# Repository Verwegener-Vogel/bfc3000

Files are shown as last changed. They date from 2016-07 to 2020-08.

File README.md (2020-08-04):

# bfc3000
## Watch and analyze your [local wild bird's](https://upload.wikimedia.org/wikipedia/commons/8/86/Eurasian_blue_tit_Lancashire.jpg) eating habits
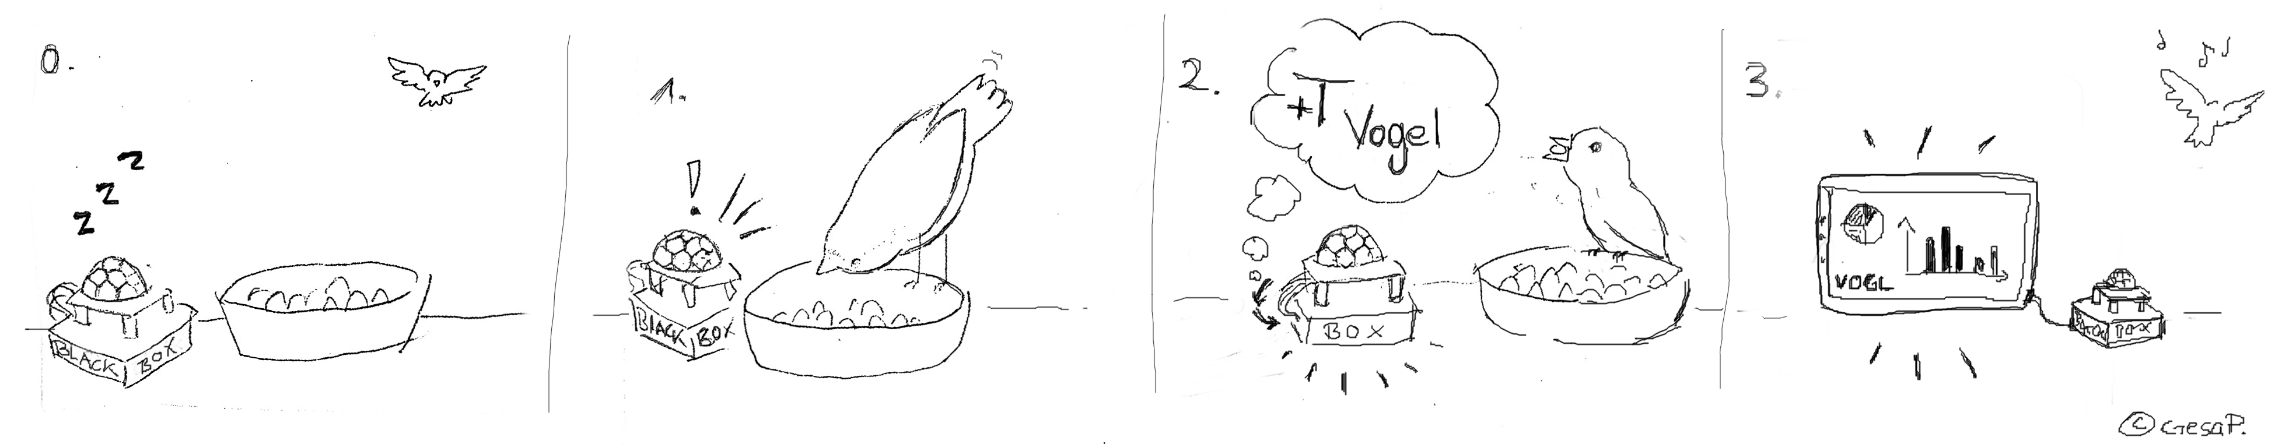
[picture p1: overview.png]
Overview


### Aim 
Writing a time stamp over multi week time frames. Timestamped entries are written by wild bird's setting off a motion
sensor. The timestamps are made up into some kind of diagrams or other visualization.
The device is power independent through piggybacking on a solar charged battery powered movement detection LED array.
Total cost should be below $50.

### Usage

You need to check out this repo first:

```
$ git clone git@github.com:barde/bfc3000.git
```

However, before you compile this sketch you need to create a file 
"config.h" with your own config values like this: 

```
#ifndef WIFI_SSID
#define WIFI_SSID "MY-WIFI-SSID"
#endif

#ifndef WIFI_PASSWORD
#define WIFI_PASSWORD "MY-WIFI-PASSWORD"
#endif

#ifndef PHANT_HOST
#define PHANT_HOST "PHANT_HOST"
#endif

#ifndef PHANT_PORT
#define PHANT_PORT 80
#endif

#ifndef PUBLIC_KEY
#define PUBLIC_KEY "PUBLIC_KEY"
#endif

#ifndef PRIVATE_KEY
#define PRIVATE_KEY "PRIVATE_KEY"
#endif

```

You have to chose a hardware platform:

### Different versions and technologies

There are two different versions of this project. It evolved after I got from the prototype to a soldered and fixed
part. The main reasons were the expanded capabilities of the ESP8266. I could save some hardware parts, too.

Todo: More description about:
Atmel328 with additional hardware for timekeeping and logfile saving local saving version vs ESP8266 with IoT webservice
connection and on board SNTP.

### Used hardware for Atmel 328 version
|Hardware|Note|Price|My Source|
|---|---|----:|---|
|PIR sensor|low active so possible to mock with a push button |$1|[Aliexpress](http://www.aliexpress.com/item/1pcs-High-Quality-HC-SR501-Infrared-PIR-Motion-Sensor-Module-For-Arduino-Raspberry-pi/32558562655.html) |
|OpenLog & SD card|I had this lying around but any cheap copy is fine|$20|Sparkfun| 
|TinyRTC||$0.6|[Aliexpress](http://www.aliexpress.com/item/Free-shipping-20pcs-lot-The-Tiny-RTC-I2C-modules-24C32-memory-DS1307-clock-RTC-module-for/1876368739.html)|
|Atmel 328P|using the bare chip allows us to utilize the full potential of the power saving|$2|| 
|Solar lamp|a weather proof nice case and solar rechargeable battery power supply|$3|[Aliexpress](http://www.aliexpress.com/item/New-Arrival-Solar-Power-Panel-6-LED-Light-Sensor-Waterproof-Outdoor-Fence-Garden-Pathway-Wall-Lamp/32456071230.html)|
|5V voltage boost||$1||
|100nf ceramic capacitor|For smoothing out the power spike during runtime|$0.1|| 

Expect some soldering for the headers and connections.

### Used hardware for ESP8266 version
|Hardware|Note|Price|My Source|
|---|---|----:|---|
|PIR sensor|low active so possible to mock with a push button |$1|[Aliexpress](http://www.aliexpress.com/item/1pcs-High-Quality-HC-SR501-Infrared-PIR-Motion-Sensor-Module-For-Arduino-Raspberry-pi/32558562655.html) |
|WeMos D1 ||$4|[Aliexpress](http://www.aliexpress.com/store/1331105) |
|WeMos battery shield |stackable with other WeMos parts|$2|[Aliexpress](http://www.aliexpress.com/store/1331105) |
|Solar lamp|a weather proof nice case and solar rechargeable battery power supply|$3|[Aliexpress](http://www.aliexpress.com/item/New-Arrival-Solar-Power-Panel-6-LED-Light-Sensor-Waterproof-Outdoor-Fence-Garden-Pathway-Wall-Lamp/32456071230.html)|

This is the improved hardware for this project. No need for a RTC as the WeMos seems to be pretty good at keeping time.
The wireless capability can be used to get the actual time from SNTP. Even the Micro SD is not really necessary due
to pushing the data to some IoT service.

Noteworthy fact: the deep sleep functionality of the ESP8266/WeMos is **much** easier to use compared to the
Atmel/Arduino library.

As for learning about this powerful and cheap platform I recommend this insightful [YT
channel](https://www.youtube.com/channel/UCu7_D0o48KbfhpEohoP7YSQ) in combination with his code:
[SensorsIOT](https://github.com/sensorsiot).
For a future improvement the upcoming [ESP32](https://espressif.com/en/products/hardware/esp32/overview) will 
probably be used in combination with the BLE for more power saving.

### Modifications to hardware, software and libs

#### Parasitic casing and power source

Gut the solar LED lamp and solder a connector for easy access from the step up converter to 5V.
As the sensors utilize 5V I keep the power on two separate rails on my perfboard.

### Modifications to hardware, software and libs for 328 version

#### Connector on base board

The OpenLog and TinyRTC modules are plugged directly from their female header into a male socket. This puts stability
and reduces cable clutter in the case.

#### ICSP header

Even the small space on the board leaves some place for a 6 pin ICSP connector for later reprogramming.

#### Using the on-chip 8 MHz oscillator

Some tweaking allow to save the external 16Mhz oscillator.
[This](https://www.arduino.cc/en/Tutorial/ArduinoToBreadboard) 
tutorial was tested successfully. There are sources claiming major power saving. No draw backs with this project as
there are not time critical libraries used.

#### Firmware update for the OpenLog
Using [this instruction](https://learn.sparkfun.com/tutorials/openlog-hookup-guide) you should update to the newest
firmware. It is required to use full FAT32 formatted cards.

### Modifications to hardware, software and libs for ESP8266 version

#### IoT Service

For easier logging and saving in complexity and hardware parts a IoT service is used. (http://data.sparkfun.com) is used
by this sketch. The service is a RESTful web service and I recommend using the GET method.

Sparkfun has a in build time stamp functionality. With this feature enable there is even room to scrap the SNTP and use
the web service's time. The ESP sketch uses both variants.

#### Nearest NTP server

For best results you should change the NTP server pool to your nearest location. The default is the German NTP pool.

### Schematics for 328 version ###
Downloadable from [this repository](bfc3000_atmega328.fzz). The software used is free and called [Fritzing](http://fritzing.org).
Not in best shape as there is only one board produced until now.

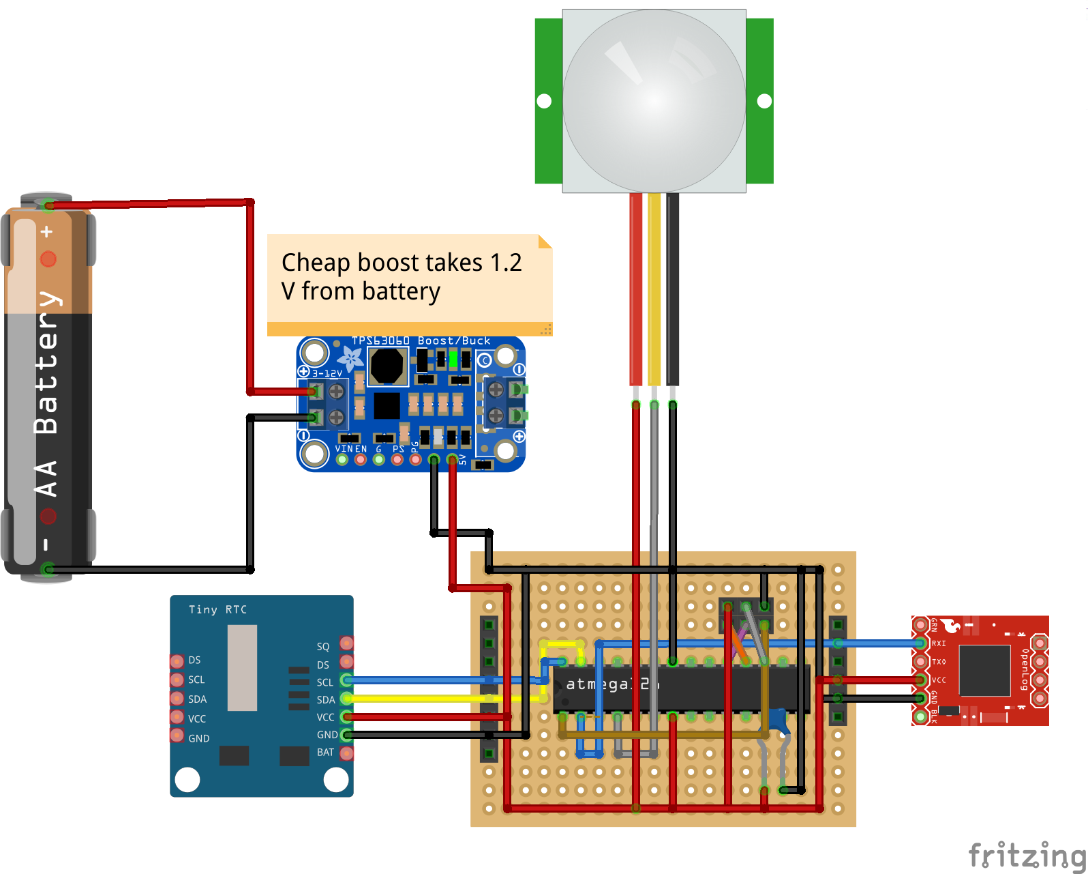
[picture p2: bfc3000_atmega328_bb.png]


### Schematics for ESP8266 version ###
Downloadable from [this repository](bfc3000_wemos.fzz).

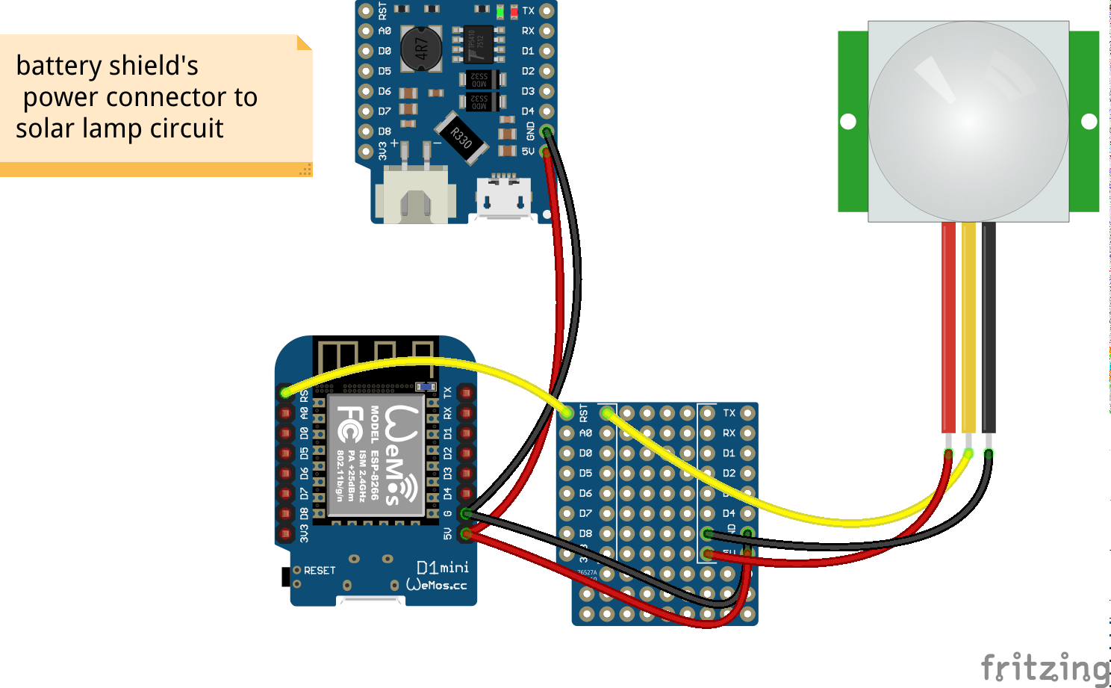
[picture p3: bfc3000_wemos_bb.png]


### Prototype
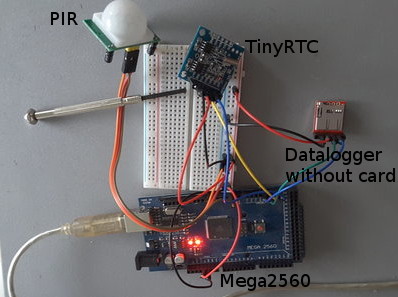
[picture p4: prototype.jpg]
Prototype with ATMEGA2560 boad


Using an ATMEGA2560 for prototyping has the big improvement of multiple serial ports. One for debugging and other for
the devices, e.g. the OpenLog which communicates over Serial.

It was somewhat fuzzy to get the OpenLog going with my el-cheapo Chinese MicroSD. Firstly, the sensor was blinking
thrice (card error) with its default FAT32 system. I repartitioned to FAT16 and decreased the partition size. It worked
but the card was not removable during a power cycle.

The solution: a firmware update. You need some TTL converter like FTDI to USB or some 
[cheaper
version](http://www.aliexpress.com/item/Free-Shipping-1pcs-FT232RL-FTDI-USB-3-3V-5-5V-to-TTL-Serial-Adapter-Module/32481520135.htm).
Following [this instruction](https://learn.sparkfun.com/tutorials/openlog-hookup-guide) for reprogramming the on board Atmega328 is straight forward.
After flashing it flawlessly wrote to the full sized FAT32 partitioned card.

Putting the board into production was not considered due to the price limit of this project. After a manual setup on a
permaboard the author switched to a WeMos with shield. Reasons were the improved capabilities and some saved parts.

### Power supply
Due to its size and small expected power consumption it is fit to be powered by a 1.2V NiMh battery. For power
harvesting I reuse a small [solar powered lamp with an included rechargable
battery](http://www.aliexpress.com/item/New-Arrival-Solar-Power-Panel-6-LED-Light-Sensor-Waterproof-Outdoor-Fence-Garden-Pathway-Wall-Lamp/32456071230.html).
Quite nice for $3 as there is lavish space inside for my own sensors and the board. The casing seems
watertight. I put the step up converter in parallel to the battery and used some left over JST connectors.

### External Libraries
[SNTPtime](http://github.com/SensorsIot/SNTPtime)

### Demo

An old output stream for comparing your results is available
[here](https://data.sparkfun.com/output/jqyY35p6V6COWKOw8q8o?timezone=Europe/Berlin).

### Publisher
Part of the projects which are created by: Verwegener Vogel e.V. , a society of bird-loving-people

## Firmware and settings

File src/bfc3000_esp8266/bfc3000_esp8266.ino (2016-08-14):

/*  bfc3000 for ESP8266 - partly sophisticated bird feeding measurement
    Copyright (C) 2016 Bartholomäus Dedersen

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
    You should have received a copy of the GNU General Public License
    along with this program.  If not, see <http://www.gnu.org/licenses/>.
*/
#include <Wire.h>
#include "RTClib.h"
#include <ESP8266WiFi.h>
#include <SNTPtime.h>


// set your wifi password in this header
#include "config.h"


SNTPtime NTP("2.de.pool.ntp.org");

/*
   The structure contains following fields:
   struct strDateTime
  {
  byte hour;
  byte minute;
  byte second;
  int year;
  byte month;
  byte day;
  byte dayofWeek;
  boolean valid;
  };
*/
strDateTime currentDate;
char timestamp[64];

void setup()
{

  Serial.begin(115200);
  pinMode(BUILTIN_LED, OUTPUT); 
}


void loop()
{
  Serial.println("starting bfc3000");
  connectWiFi();
  Serial.println("connected to wifi");

 // set internal clock with SNTP server's time
  while (!NTP.setSNTPtime()) 
  {
      Serial.println("Trying to set time.."); // set internal clock
  }

  currentDate = NTP.getTime(1.0, 1);
  sprintf(timestamp,"%04i;%02d;%02d;%02d;%02d;%02d", currentDate.year, currentDate.day, currentDate.month, currentDate.hour, currentDate.minute, currentDate.second);
  Serial.print("Timestamp: ");
  Serial.println(timestamp);

  postToPhant();
  Serial.println("going to sleep");
  
  // sleep wakes on low edge on RST pin
  ESP.deepSleep(0);
}

// connect wifi and return when connected
void connectWiFi()
{
  Serial.print("connecting to wifi");
  WiFi.mode(WIFI_STA);
  WiFi.begin(WIFI_SSID, WIFI_PASSWORD);

  while (WiFi.status() != WL_CONNECTED)
  {
    Serial.print('.');
    delay(500);
  }

  Serial.println(" - connection successful");
}

// Posts timestamp and unique id from device to phant service
void postToPhant()
{
  // LED turns on when we enter, it'll go off when we
  // successfully post.
  digitalWrite(BUILTIN_LED, HIGH);

  // get unique identifier by MAC of posting device
  uint8_t mac[WL_MAC_ADDR_LENGTH];
  WiFi.macAddress(mac);
  String macID = String(mac[WL_MAC_ADDR_LENGTH - 2], HEX) +
                 String(mac[WL_MAC_ADDR_LENGTH - 1], HEX);
  macID.toUpperCase();
  String postedID = "wemos-" + macID;

  // Use WiFiClient class to create TCP connections
  WiFiClient client;
  const int httpPort = 80;
  if (!client.connect(PHANT_HOST, PHANT_PORT)) {
    Serial.println("connection failed");
    return;
  }
  
  // We now create a URI for the request
  String url = "/input/";
  url += PUBLIC_KEY;
  url += "?private_key=";
  url += PRIVATE_KEY;
  url += "&id=";
  url += postedID;
  url += "&feedtime=";
  url += timestamp;
  
  Serial.print("Requesting URL: ");
  Serial.println(url);
  
  // This will send the request to the server
  client.print(String("GET ") + url + " HTTP/1.1\r\n" +
               "Host: " + PHANT_HOST + "\r\n" + 
               "Connection: close\r\n\r\n");
  delay(10);
    
  Serial.println("closing connection");

  // Before we exit, turn the LED off.
  digitalWrite(BUILTIN_LED, LOW);
}

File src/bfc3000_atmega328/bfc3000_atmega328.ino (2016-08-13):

/*  bfc3000 - partly sophisticated bird feeding measurement
 *  
 *  Glue for sensors to measure bird feeding pattern with a low power embedded board.
 *  Sleeps in deep sleep until the bird is detected by a PIR sensor.
 *  Writes a timestamp to a SD card for later data analysis.
 *  
 * Sleep code from http://playground.arduino.cc/Learning/ArduinoSleepCode
 * Copyright (C) 2016 Bartholomäus Dedersen
 * 
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
 *  You should have received a copy of the GNU General Public License
 *  along with this program.  If not, see <http://www.gnu.org/licenses/>.
 */
#include <Wire.h>
#include "RTClib.h"
#include <avr/sleep.h>

 
int wakePin = 2;
int sdreaderVccPin = 7;

RTC_DS1307 RTC;
 
void wakeUpNow()
{
  // nop
}
 
void setup()
{
  pinMode(wakePin, INPUT_PULLUP);
  pinMode(sdreaderVccPin, OUTPUT);

  digitalWrite(sdreaderVccPin, LOW);
 
  Serial.begin(9600);
 
  Wire.begin();
  RTC.begin();
 
  if (! RTC.isrunning()) {
    Serial.println("RTC is NOT running!");
    // following line sets the RTC to the date & time this sketch was compiled
    //RTC.adjust(DateTime(__DATE__, __TIME__));
  }
 
  /* Now it is time to enable an interrupt. In the function call
   * attachInterrupt(A, B, C)
   * A   can be either 0 or 1 for interrupts on pin 2 or 3.  
   *
   * B   Name of a function you want to execute while in interrupt A.
   *
   * C   Trigger mode of the interrupt pin. can be:
   *             LOW        a low level trigger
   *             CHANGE     a change in level trigger
   *             RISING     a rising edge of a level trigger
   *             FALLING    a falling edge of a level trigger
   *
   * In all but the IDLE sleep modes only LOW can be used.
   */
 
  attachInterrupt(0, wakeUpNow, LOW); // use interrupt 0 (pin 2) and run function
                                      // wakeUpNow when pin 2 gets LOW
}
 
void sleepNow()         // here we put the arduino to sleep
{
    /* Now is the time to set the sleep mode. In the Atmega8 datasheet
     * http://www.atmel.com/dyn/resources/prod_documents/doc2486.pdf on page 35
     * there is a list of sleep modes which explains which clocks and
     * wake up sources are available in which sleep mode.
     *
     * In the avr/sleep.h file, the call names of these sleep modes are to be found:
     *
     * The 5 different modes are:
     *     SLEEP_MODE_IDLE         -the least power savings
     *     SLEEP_MODE_ADC
     *     SLEEP_MODE_PWR_SAVE
     *     SLEEP_MODE_STANDBY
     *     SLEEP_MODE_PWR_DOWN     -the most power savings
     *
     * For now, we want as much power savings as possible, so we
     * choose the according
     * sleep mode: SLEEP_MODE_PWR_DOWN
     *
     */  
    set_sleep_mode(SLEEP_MODE_PWR_DOWN);   // sleep mode is set here
 
    sleep_enable();          // enables the sleep bit in the mcucr register
                             // so sleep is possible. just a safety pin
 
    /* Now it is time to enable an interrupt. We do it here so an
     * accidentally pushed interrupt button doesn't interrupt
     * our running program. if you want to be able to run
     * interrupt code besides the sleep function, place it in
     * setup() for example.
     *
     * In the function call attachInterrupt(A, B, C)
     * A   can be either 0 or 1 for interrupts on pin 2 or 3.  
     *
     * B   Name of a function you want to execute at interrupt for A.
     *
     * C   Trigger mode of the interrupt pin. can be:
     *             LOW        a low level triggers
     *             CHANGE     a change in level triggers
     *             RISING     a rising edge of a level triggers
     *             FALLING    a falling edge of a level triggers
     *
     * In all but the IDLE sleep modes only LOW can be used.
     */
 
    attachInterrupt(0,wakeUpNow, LOW); // use interrupt 0 (pin 2) and run function
                                       // wakeUpNow when pin 2 gets LOW
 
    sleep_mode();            // here the device is actually put to sleep!!
                             // THE PROGRAM CONTINUES FROM HERE AFTER WAKING UP
 
    sleep_disable();         // first thing after waking from sleep:
                             // disable sleep...
    detachInterrupt(0);      // disables interrupt 0 on pin 2 so the
                             // wakeUpNow code will not be executed
                             // during normal running time.
 
}
 
void loop()
{
  showTime();

  // wait until button gets released
  while(digitalRead(wakePin) == false)
  {
  }

  // real sensor bounces. maybe some wait before shutdown?
  // delay(5000);
  
  sleepNow();
}

void showTime() {
  // Power additional devices
   digitalWrite(sdreaderVccPin, HIGH);
   Serial1.begin(115200); 
  
   DateTime now = RTC.now();
   char timestamp[64];
   
   sprintf(timestamp,"%04i;%02i;%02i;%02i;%02i;%02i", now.year(), now.day(), now.month(), now.hour(), now.minute(), now.second());

   Serial.println(timestamp);
   
   Serial1.println(timestamp);
   Serial.flush();
   
   Serial1.end();
   digitalWrite(sdreaderVccPin, LOW);
 }
 

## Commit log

2016-07-22 prototype and reflashing openlog
2016-07-22 prototype typo
2016-07-23 ICSP, decoupling and more parts
    [bfc3000.fzz]
2016-08-07 changed hardware to wemos
    [bfc3000.fzz, bfc3000_atmega328.fzz, bfc3000_wemos.fzz]
2016-08-13 esp8266 updates from first prototype
2016-08-13 less sd more iot webservice
    [bfc3000_wemos.fzz]

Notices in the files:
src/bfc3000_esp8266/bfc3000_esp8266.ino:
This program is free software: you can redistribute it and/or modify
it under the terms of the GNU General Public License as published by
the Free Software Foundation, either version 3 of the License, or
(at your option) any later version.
